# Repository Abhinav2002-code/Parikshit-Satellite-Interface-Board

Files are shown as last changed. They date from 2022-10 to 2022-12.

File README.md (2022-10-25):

# PA Interface Board

This is the Interface board for performance  
assurance of the Parikshit Student Satellite.

## About the project

The Parikshit Student satellite is a team of 25 undergraduates skilled in building nanosatellites.  
This PCB is a card used as an interface between  
the testing jigs in the teams lab and the nanosatellite system.

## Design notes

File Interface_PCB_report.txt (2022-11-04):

PCB statistics report
=====================
- Date: 03-11-2022 20:04:57
- Project: Interface_PCB
- Board name: Interface_PCB

Board
-----
- Width: 1822.62 mils
- Height: 1877.36 mils
- Area: 3204333.08 sq. mils

Pads
----
- Through hole: 3
- SMD: 180
- Connector: 0
- NPTH: 4

Vias
----
- Through vias: 46
- Blind/buried: 0
- Micro vias: 0

Components
----------

| | Front Side | Back Side | Total |
|---|---|---|---|
|THT: | 1  | 0  | 1  |
|SMD: | 37  | 0  | 37  |
|Total:  | 38  | 0  | 38  |
| | | | |

Drill holes
-----------

| Count | Shape | X Size | Y Size | Plated | Via/Pad | Start Layer | Stop Layer |
|---|---|---|---|---|---|---|---|
| 42 | Round | 15.75 mils | 15.75 mils | PTH | Via | F.Cu | B.Cu |
| 4 | Round | 82.68 mils | 82.68 mils | NPTH | Pad | F.Cu | B.Cu |
| 4 | Round | 11.81 mils | 11.81 mils | PTH | Via | F.Cu | B.Cu |
| 2 | Round | 51.18 mils | 51.18 mils | PTH | Pad | F.Cu | B.Cu |
| 1 | Round | 47.64 mils | 47.64 mils | PTH | Pad | F.Cu | B.Cu |

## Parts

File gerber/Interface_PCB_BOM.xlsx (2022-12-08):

Id | Quantity | Designator | Package | Designation | Supplier and ref
1 | 4 | J1,J2,J3,J4 | 502382-0470 | Conn_01x04 | element14 - https://in.element14.com/molex/502382-0470/connector-rcpt-4pos-1row-1-25mm/dp/1620786?st=5023820470
2 | 4 | CB3,CB2,CB1,CB4 | C_0805_2012Metric | 4.7u | mouser - https://www.mouser.in/ProductDetail/KEMET/C0805C475K3RACTU?qs=PzGy0jfpSMsRb1o8vMQxfQ%3D%3D
3 | 4 | H2,H3,H1,H4 | MountingHole_2.1mm | MountingHole
4 | 5 | CD6,CD3,CD5,CD2,CD4 | C_0402_1005Metric | 100n | mouser - https://www.mouser.in/ProductDetail/KEMET/C0402C104M4PACTU?qs=K5ytOU5dogo1QkNDOJRLDg%3D%3D
5 | 2 | CMS1,CMS3 | C_0805_2012Metric | 10n | mouser - https://www.mouser.in/ProductDetail/KEMET/C0805C103K8RACAUTO?qs=MyNHzdoqoQL%2F3d5ufVgX2g%3D%3D
6 | 1 | IC1 | QFP50P1200X1200X160-64N | STM32L412RBT6P | mouser - https://www.mouser.in/ProductDetail/STMicroelectronics/STM32L412RBT6P?qs=l7cgNqFNU1hh%252BU1wOZs5Xg%3D%3D
7 | 1 | CMS2 | C_0805_2012Metric | 1u | mouser - https://www.mouser.in/ProductDetail/KEMET/C0805X105K5RACAUTO?qs=HBWAp0VN4Rg97tWg6%252BgIPg%3D%3D
8 | 1 | J6 | 693072010801 | Micro_SD_Card | mouser - https://www.mouser.in/ProductDetail/Wurth-Elektronik/693072010801?qs=7gQLVZk5cPmw4uU1mAcUFg%3D%3D
9 | 3 | CR2,CR1,CR3 | C_0402_1005Metric | 22uF | mouser - https://www.mouser.in/ProductDetail/Taiyo-Yuden/AMK105EBJ226MV-F?qs=gZXFycFWdAObGy%252BzTmkIrw%3D%3D
10 | 1 | Y2 | ECS80830QVSTR | Crystal | mouser - https://www.mouser.in/ProductDetail/ECS/ECS-80-8-30Q-VS-TR?qs=T3oQrply3y8AmzaMN9qXDQ%3D%3D
11 | 1 | RExt1 | R_0603_1608Metric | 2K | mouser - https://www.mouser.in/ProductDetail/Bourns/CR0603-JW-202ELF?qs=QNvGIbmBFedJvqrSZNeMIw%3D%3D
12 | 2 | R2,R1 | R_0805_2012Metric | 1k | mouser - https://www.mouser.in/ProductDetail/Bourns/CR0805-FX-1001ELF?qs=tknLyCMIRbOJasvgRv5Bdg%3D%3D
13 | 2 | Cl1,Cl2 | C_0402_1005Metric | 2pF | mouser - https://www.mouser.in/ProductDetail/KEMET/C0402C209D5GACAUTO?qs=Cqqh%252BS766wl%2FF1D1Q0LwKg%3D%3D
14 | 1 | Y1 | ABS05W32768KHZD2T | Crystal | element14 - https://in.element14.com/abracon/abs05-32-768khz-t/crystal-32-768khz-12-5pf-1-6-x/dp/2467859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
15 | 2 | RSPI1,RSPI2 | R_0402_1005Metric | 1K | mouser - https://www.mouser.in/ProductDetail/Bourns/CR0402AFX-1001GLF?qs=GedFDFLaBXGtEgTtdRRFew%3D%3D
16 | 2 | D2,D1 | LED_0805_2012Metric | LED_Small | mouser - https://www.mouser.in/ProductDetail/Wurth-Elektronik/150080BS75000?qs=2kOmHSv6VfT2tBo3UPVqAQ%3D%3D
17 | 2 | Cl4,Cl3 | C_0402_1005Metric | 10pF | mouser - https://www.mouser.in/ProductDetail/KEMET/C0402C100K5RACAUTO?qs=hzBznG4dWXWvk2ClWTGJYg%3D%3D
18 | 2 | LR1,LMS1 | L_0805_2012Metric | 39nH | mouser - https://www.mouser.in/ProductDetail/ABRACON/AIMC-0805-39NJ-T?qs=1vO2EIVe%252BY6yKg%252Bn%252BCAmog%3D%3D
19 | 1 | CD1 | C_0402_1005Metric | 4.7u | mouser - https://www.mouser.in/ProductDetail/KEMET/C0402C475M9PACTU?qs=x4XeXhDQKnr0GX0Xu9DUoQ%3D%3D
20 | 1 | U1 | SOT-223-3_TabPin2 | AMS1117-3.3 | electronics comp - https://www.electronicscomp.com/ams1117-3.3v-voltage-regulator-smd-sot-23-package-india
21 | 1 | J5 | FTSH10501LDVK | AVR-JTAG-10 | mouser - https://www.mouser.in/ProductDetail/Samtec/FTSH-105-01-L-DV-K?qs=%252B5JSS813miOqo3Vy%252BvhCFg%3D%3D
22 | 1 | J7 | GMCB05B11124H1EU | USB_B | mouser - https://www.mouser.in/ProductDetail/Amphenol-Commercial-Products/GMCB05B11124H1EU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
23 | 1 | NT1 | NetTie-3_SMD_Pad2.0mm | NetTie_3_Tee
24 | 1 | DEXT1 | AQ120501ETG | D_Schottky | mouser - https://www.mouser.in/ProductDetail/Littelfuse/AQ1205-01ETG?qs=TCDPyi3sCW2VfoQH%2FYUj8g%3D%3D
25 | 1 | J8 | PinHeader | Conn_01x02_Male | mouser - https://www.mouser.in/ProductDetail/Harwin/M20-9990246?qs=Jph8NoUxIfWjw4WmyRvzag%3D%3D

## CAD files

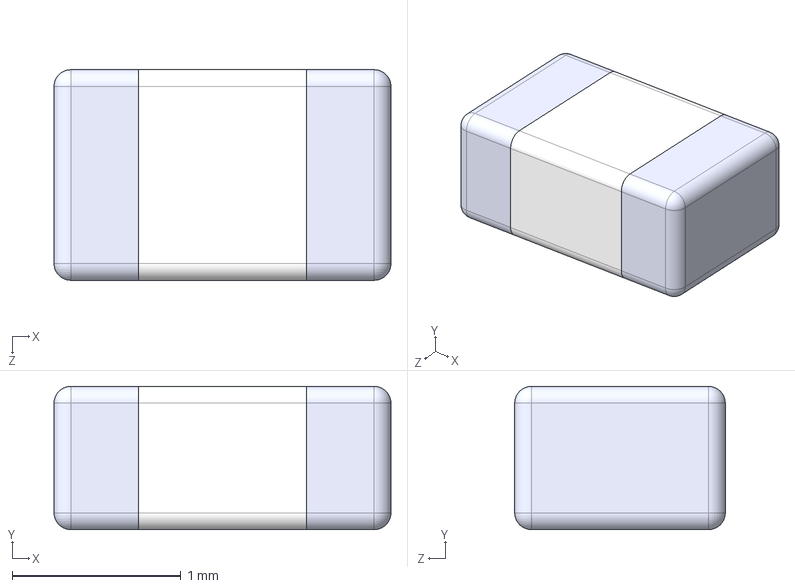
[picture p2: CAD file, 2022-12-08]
AIMC-0805-39NJ-T.STEP
2.00 x 0.85 x 1.25 mm

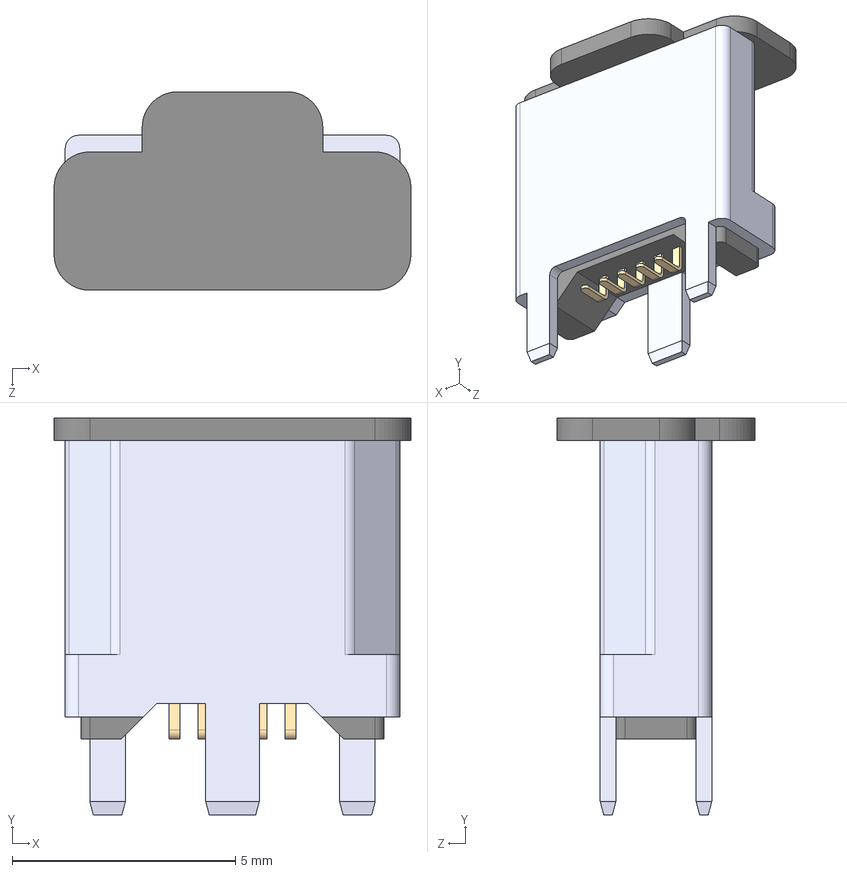
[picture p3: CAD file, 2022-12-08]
GMCB05B11124H1EU (1)/GMCB05B11124H1EU.step
8.00 x 8.90 x 4.45 mm
GMCB05B11124H1EU-Housing
GMCB05B11124H1EU-Pin x 5
GMCB05B11124H1EU-Shell

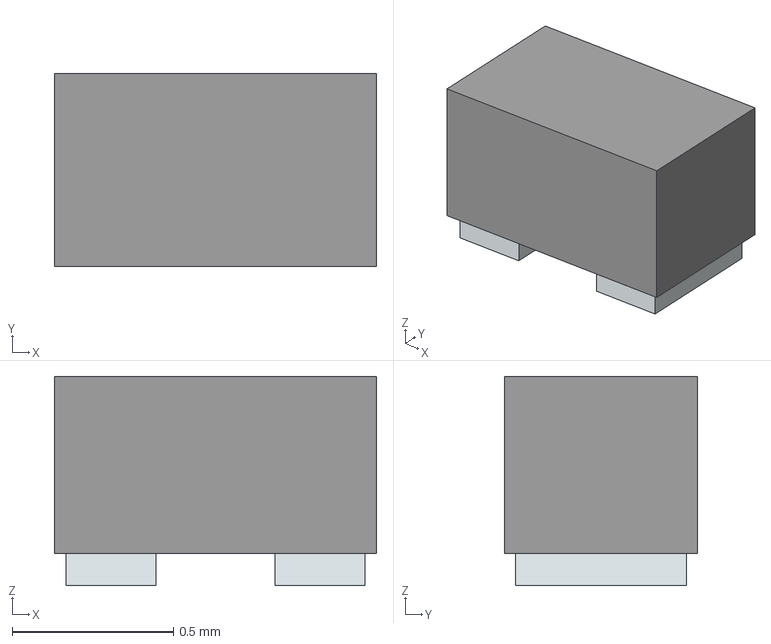
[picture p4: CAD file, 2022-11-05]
AQ1205-01ETG.stp
1.00 x 0.6 x 0.65 mm
Pins

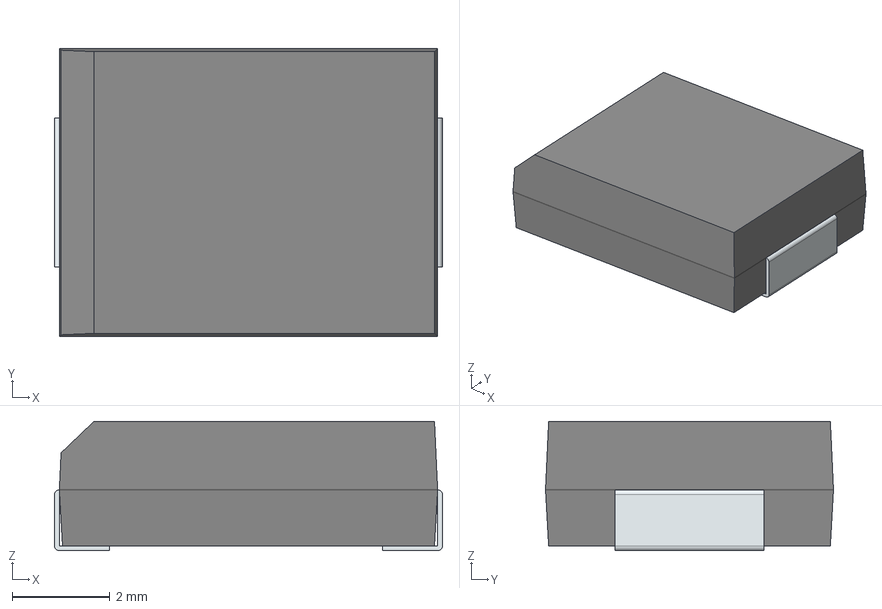
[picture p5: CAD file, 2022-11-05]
SMC50J58A.stp
7.95 x 5.90 x 2.65 mm
FilletPin1
FilletPin2

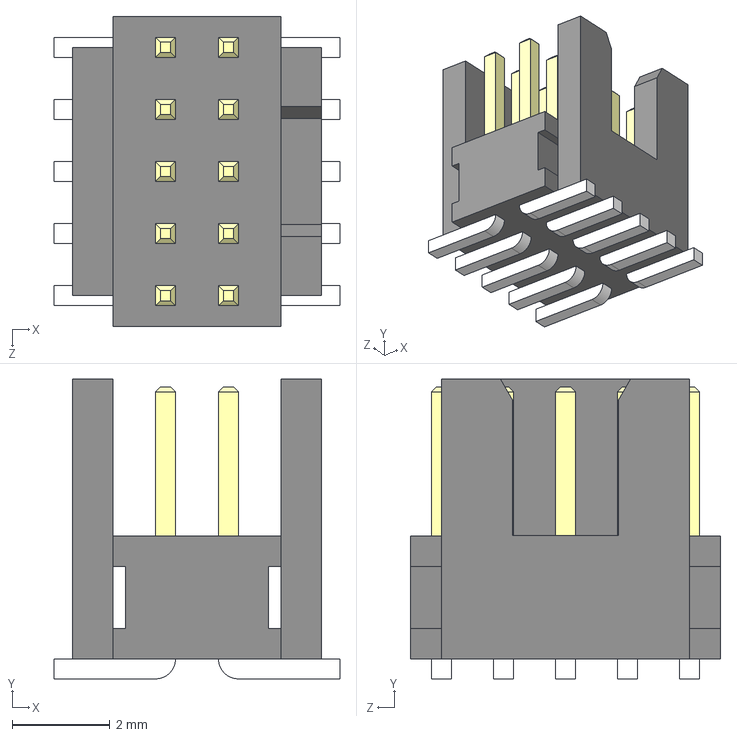
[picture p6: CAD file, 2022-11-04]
FTSH-105-01-L-DV-K.stp
5.85 x 6.13 x 6.35 mm

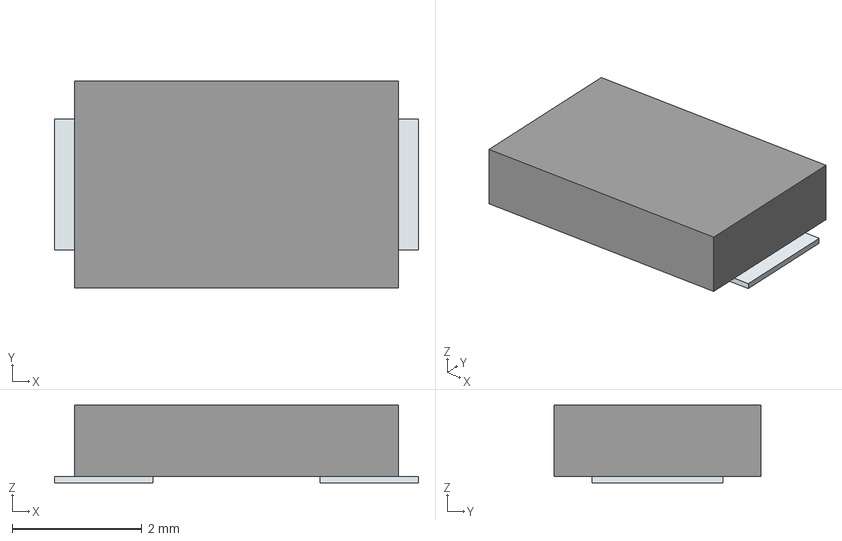
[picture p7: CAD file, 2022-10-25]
ECS-80-8-30Q-VS-TR.stp
5.62 x 3.20 x 1.20 mm
Pins

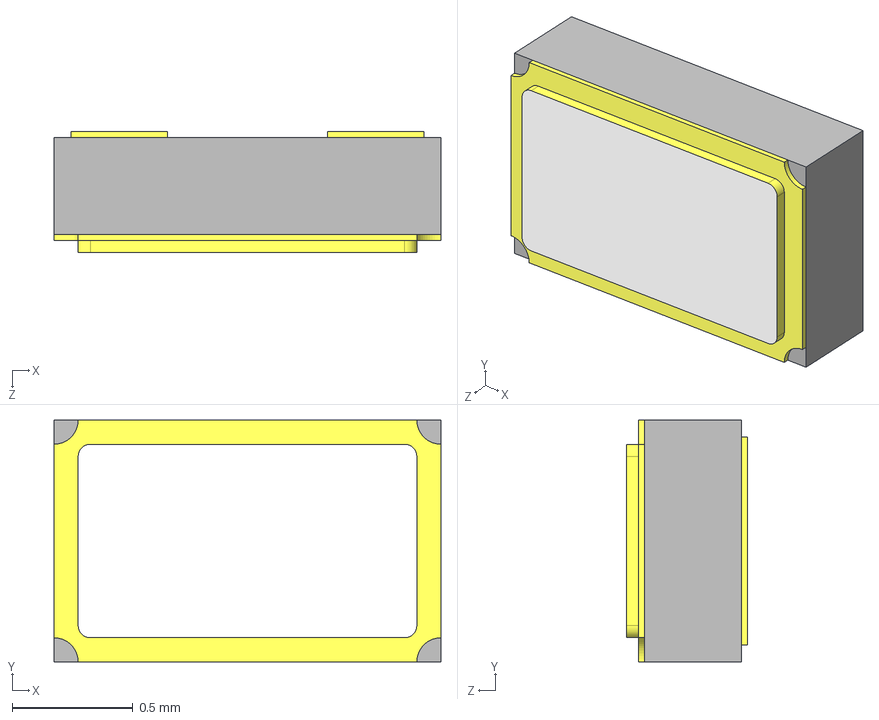
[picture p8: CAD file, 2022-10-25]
ABS05W-32.768KHZ-D-2-T.stp
1.60 x 1.00 x 0.5 mm

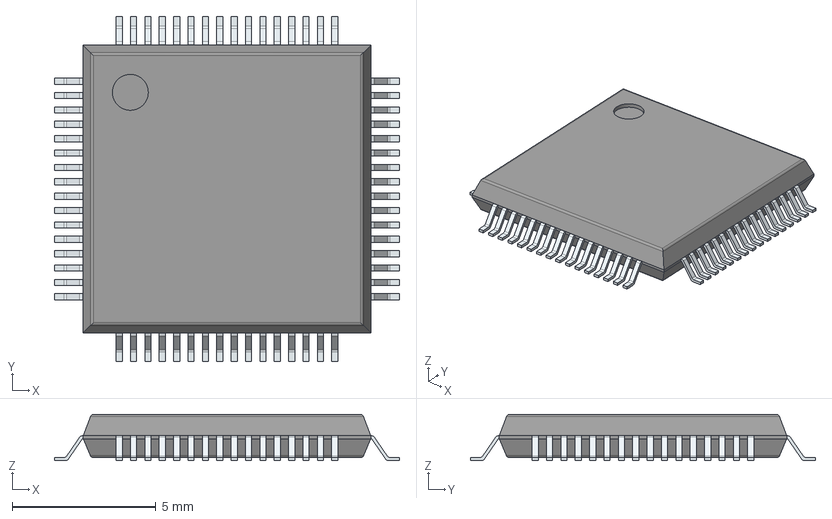
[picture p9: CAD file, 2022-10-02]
STM32L412RBT6P.stp
12.0 x 12.0 x 1.60 mm
PinsArrayLR
PinsArrayTB

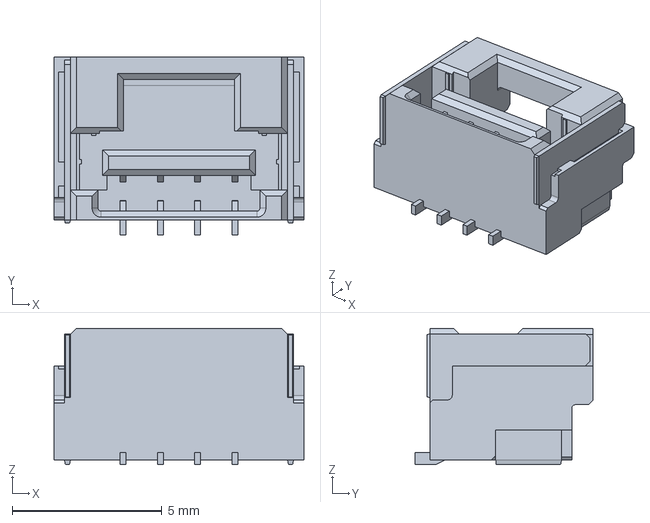
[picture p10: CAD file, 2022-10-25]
502382-0470.stp
8.35 x 5.94 x 4.55 mm

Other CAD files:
STM32L412RBT6P/Allegro/qfp50p1200x1200x160-64n.psm
STM32L412RBT6P/DEHDL/stm32l412rbt6p/chips/chips.prt

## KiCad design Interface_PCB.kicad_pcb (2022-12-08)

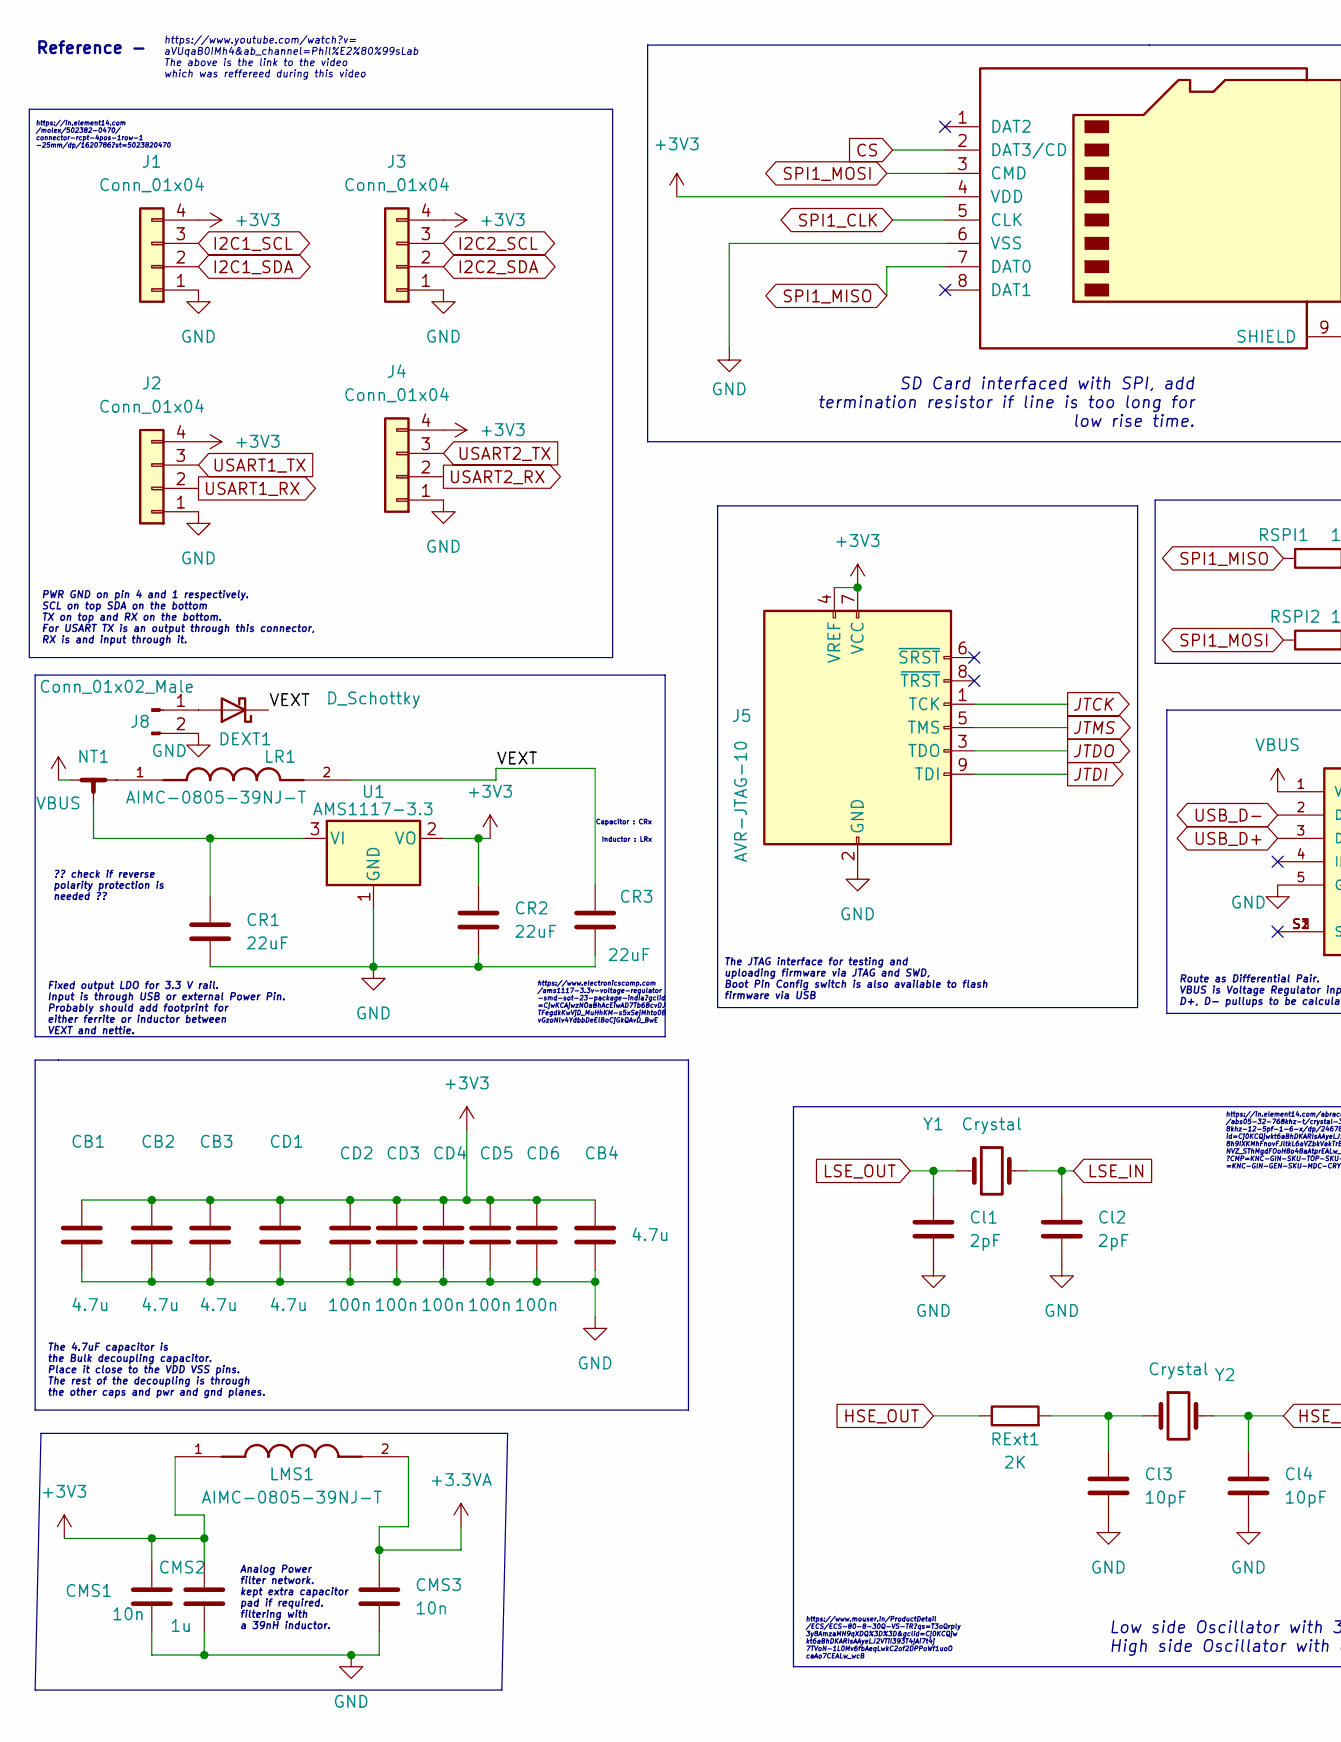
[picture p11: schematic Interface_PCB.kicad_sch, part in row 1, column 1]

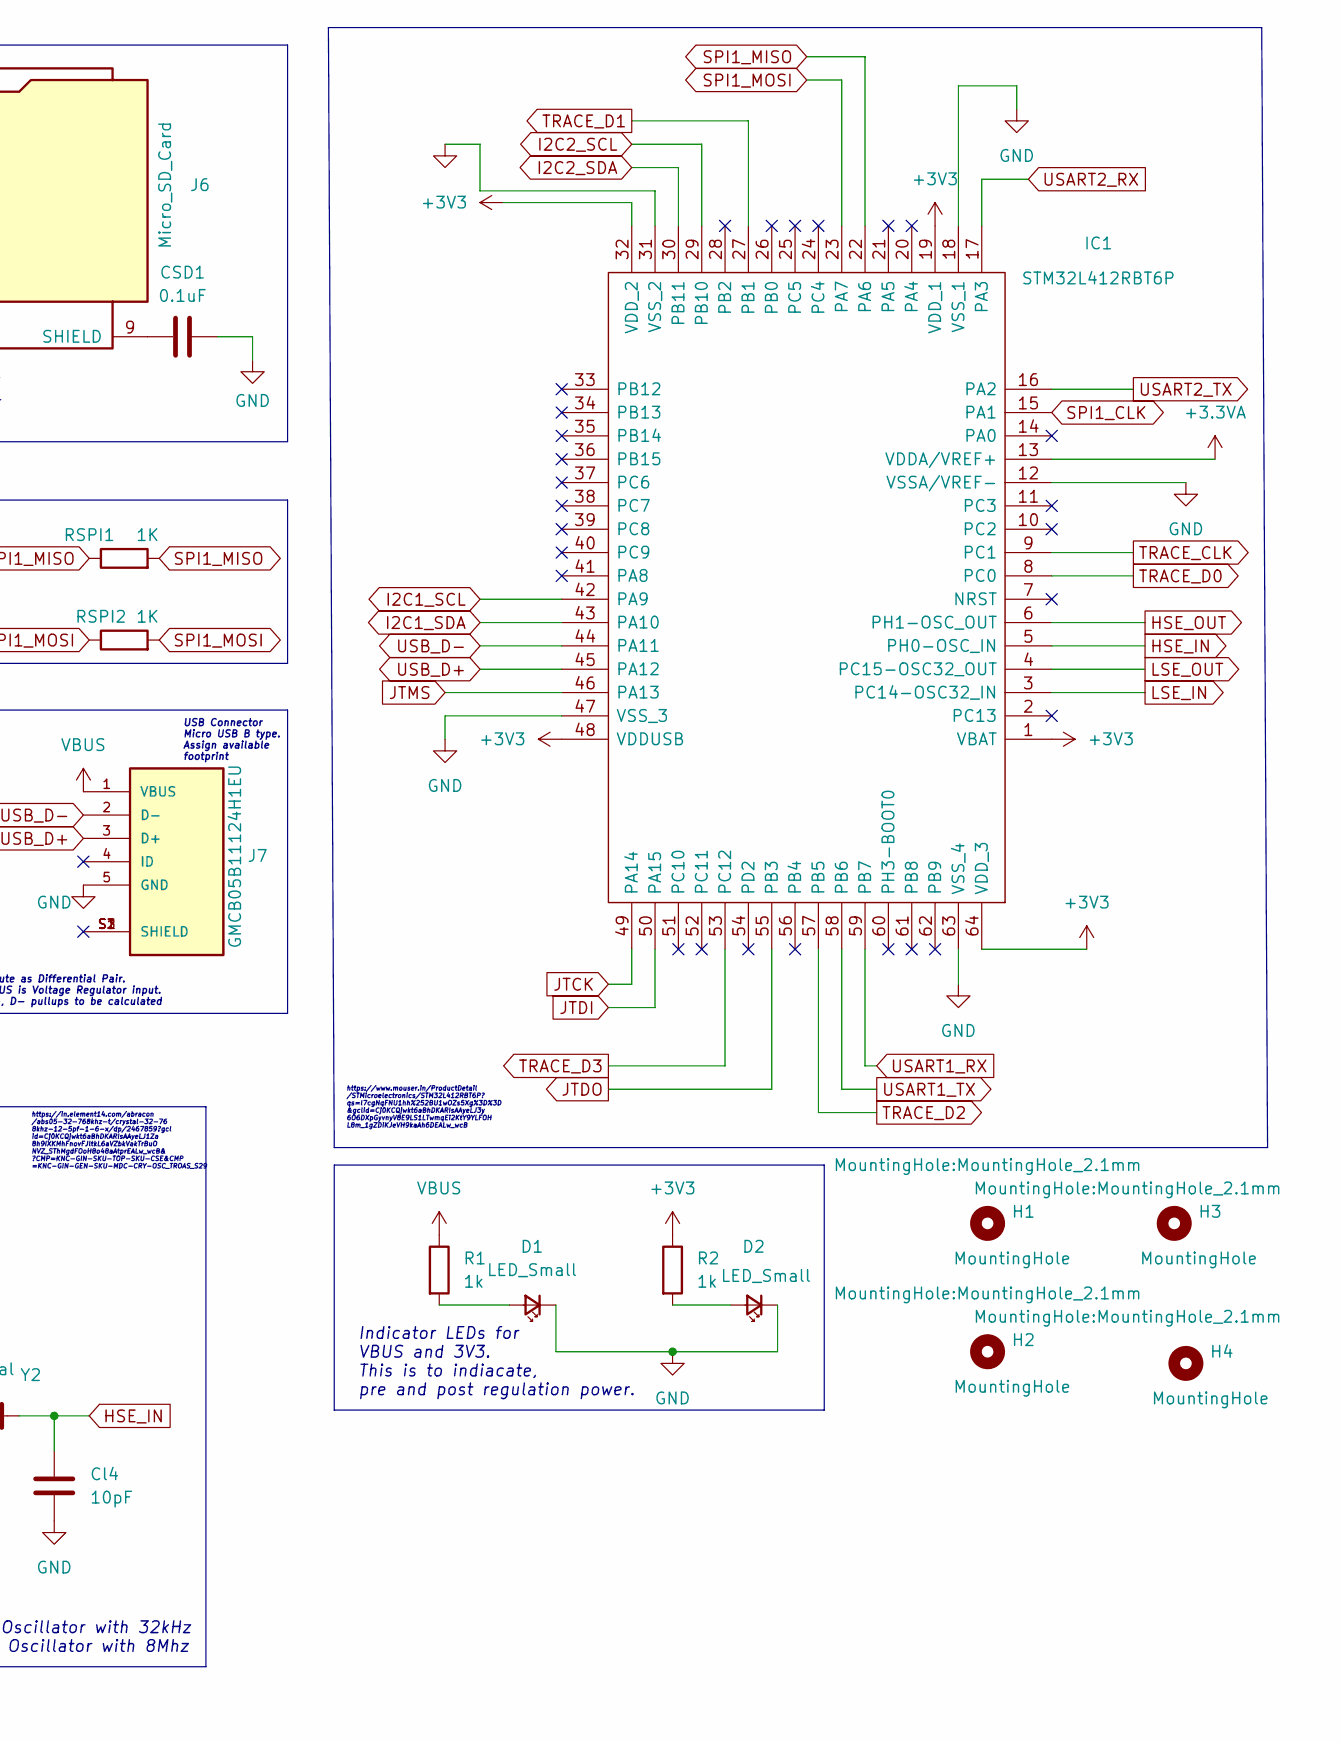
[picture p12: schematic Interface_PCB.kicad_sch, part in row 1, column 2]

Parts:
CB1, CB2, CB3, CB4: 4.7u; C_0805_2012Metric
CD1: 4.7u; C_0402_1005Metric
CD2, CD3, CD4, CD5, CD6: 100n; C_0402_1005Metric
CMS1, CMS3: 10n; C_0805_2012Metric
CMS2: 1u; C_0805_2012Metric
CR1, CR2, CR3: 22uF; C_0402_1005Metric
CSD1: 0.1uF; C_0402_1005Metric
Cl1, Cl2: 2pF; C_0402_1005Metric
Cl3, Cl4: 10pF; C_0402_1005Metric
D1, D2: LED_Small; LED_0805_2012Metric
DEXT1: D_Schottky; AQ120501ETG
H1, H2, H3, H4: MountingHole; MountingHole_2.1mm
IC1: STM32L412RBT6P; QFP50P1200X1200X160-64N; Mouser Part Number 511-STM32L412RBT6P
J1, J2, J3, J4: Conn_01x04; 502382-0470
J5: AVR-JTAG-10; FTSH10501LDVK
J6: Micro_SD_Card; 693072010801
J7: GMCB05B11124H1EU; AMPHENOL_GMCB05B11124H1EU; PARTREV C
J8: Conn_01x02_Male; PinHeader_1x02_P2.54mm_Vertical
LMS1: AIMC-0805-39NJ-T; INDC2012X105N
LR1: AIMC-0805-39NJ-T; INDC2012X105N
NT1: NetTie_3_Tee; NetTie-3_SMD_Pad2.0mm
R1, R2: 1k; R_0805_2012Metric
RExt1: 2K; R_0603_1608Metric
RSPI1, RSPI2: 1K; R_0402_1005Metric
U1: AMS1117-3.3; SOT-223-3_TabPin2
Y1: Crystal; ABS05W32768KHZD2T
Y2: Crystal; ECS80830QVSTR

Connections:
+3.3VA: CMS3.1, IC1.13 (VDDA/VREF+), LMS1.2
+3V3: CB1.1, CB2.1, CB3.1, CB4.1, CD1.1, CD2.1, CD3.1, CD4.1, CD5.1, CD6.1, CMS1.1, CMS2.1, CR2.1, IC1.1 (VBAT), IC1.19 (VDD_1), IC1.32 (VDD_2), IC1.48 (VDDUSB), IC1.64 (VDD_3), J1.4, J2.4, J3.4, J4.4, J5.4 (VREF), J5.7 (VCC), J6.4 (VDD), LMS1.1, R2.1, U1.2 (VO)
/VEXT: CR3.1, DEXT1.1 (K), LR1.2
CS: J6.2 (DAT3/CD)
GND: CB1.2, CB2.2, CB3.2, CB4.2, CD1.2, CD2.2, CD3.2, CD4.2, CD5.2, CD6.2, CMS1.2, CMS2.2, CMS3.2, CR1.2, CR2.2, CR3.2, CSD1.2, Cl1.2, Cl2.2, Cl3.2, Cl4.2, D1.1 (K), D2.1 (K), IC1.12 (VSSA/VREF-), IC1.18 (VSS_1), IC1.31 (VSS_2), IC1.47 (VSS_3), IC1.63 (VSS_4), J1.1, J2.1, J3.1, J4.1, J5.2 (GND), J5.10 (GND), J6.6 (VSS), J7.5 (GND), J8.2, U1.1 (GND)
HSE_IN: Cl4.1, IC1.5 (PH0-OSC_IN), Y2.2
HSE_OUT: IC1.6 (PH1-OSC_OUT), RExt1.1
I2C1_SCL: IC1.42 (PA9), J1.3
I2C1_SDA: IC1.43 (PA10), J1.2
I2C2_SCL: IC1.29 (PB10), J3.3
I2C2_SDA: IC1.30 (PB11), J3.2
JTCK: IC1.49 (PA14), J5.1 (TCK)
JTDI: IC1.50 (PA15), J5.9 (TDI)
JTDO: IC1.55 (PB3), J5.3 (TDO)
JTMS: IC1.46 (PA13), J5.5 (TMS)
LSE_IN: Cl2.1, IC1.3 (PC14-OSC32_IN), Y1.2
LSE_OUT: Cl1.1, IC1.4 (PC15-OSC32_OUT), Y1.1
unnamed: CR1.1, NT1.3, U1.3 (VI)
unnamed: CSD1.1, J6.9 (SHIELD)
unnamed: Cl3.1, RExt1.2, Y2.1
unnamed: D1.2 (A), R1.2
unnamed: D2.2 (A), R2.2
unnamed: DEXT1.2 (A), J8.1
unnamed: LR1.1, NT1.2
SPI1_CLK: IC1.15 (PA1), J6.5 (CLK)
SPI1_MISO: IC1.22 (PA6), J6.7 (DAT0), RSPI1.1, RSPI1.2
SPI1_MOSI: IC1.23 (PA7), J6.3 (CMD), RSPI2.1, RSPI2.2
TRACE_CLK: IC1.9 (PC1)
TRACE_D0: IC1.8 (PC0)
TRACE_D1: IC1.27 (PB1)
TRACE_D2: IC1.57 (PB5)
TRACE_D3: IC1.53 (PC12)
USART1_RX: IC1.59 (PB7), J2.2
USART1_TX: IC1.58 (PB6), J2.3
USART2_RX: IC1.17 (PA3), J4.2
USART2_TX: IC1.16 (PA2), J4.3
USB_D+: IC1.45 (PA12), J7.3 (D+)
USB_D-: IC1.44 (PA11), J7.2 (D-)
VBUS: J7.1 (VBUS), NT1.1, R1.1

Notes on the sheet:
Fixed output LDO for 3.3 V rail. Input is through USB or external Power Pin. Probably should add footprint for either ferrite or inductor between VEXT and nettie.
USB Connector Micro USB B type. Assign available footprint
The JTAG interface for testing and uploading firmware via JTAG and SWD, Boot Pin Config switch is also available to flash firmware via USB
Capacitor : CRx
SD Card interfaced with SPI, add termination resistor if line is too long for low rise time.
?? check if reverse polarity protection is needed ??
Reference -
Indicator LEDs for VBUS and 3V3. This is to indiacate, pre and post regulation power.
https://www.mouser.in/ProductDetail /STMicroelectronics/STM32L412RBT6P? qs=l7cgNqFNU1hh%252BU1wOZs5Xg%3D%3D &gclid=Cj0KCQjwkt6aBhDKARIsAAyeLJ3y 6O6DXpGyvnyV8E9LS1LTwmqEi2KtY9YLFOH L8m_1gZDiKJeVH9kaAh6DEALw_wcB
https://in.element14.com/abracon /abs05-32-768khz-t/crystal-32-76 8khz-12-5pf-1-6-x/dp/2467859?gcl id=Cj0KCQjwkt6aBhDKARIsAAyeLJ1Za 8h9IXKMhFnovFJltkL6aVZbkVakTrBuO NVZ_SThMgdFOoH8o48aAtprEALw_wcB& ?CMP=KNC-GIN-SKU-TOP-SKU-CSE&CMP =KNC-GIN-GEN-SKU-MDC-CRY-OSC_TROAS_S29
https://www.youtube.com/watch?v= aVUqaB0IMh4&ab_channel=Phil%E2%80%99sLab The above is the link to the video which was reffereed during this video
Analog Power filter network. kept extra capacitor pad if required. filtering with a 39nH inductor.
Low side Oscillator with 32kHz High side Oscillator with 8Mhz
Route as Differential Pair. VBUS is Voltage Regulator input. D+, D- pullups to be calculated
https://www.mouser.in/ProductDetail /ECS/ECS-80-8-30Q-VS-TR?qs=T3oQrply 3y8AmzaMN9qXDQ%3D%3D&gclid=Cj0KCQjw kt6aBhDKARIsAAyeLJ2VTiI393T4jAi7t4j 7TVoN-1L0Mv6fbAeqLwkC2of2DPPoWf1uoO caAo7CEALw_wcB
https://www.electronicscomp.com /ams1117-3.3v-voltage-regulator -smd-sot-23-package-india?gclid =CjwKCAjwzNOaBhAcEiwAD7Tb6BcvDJ TFegdkKwVjD_MuHhKM-s5xSejMhto0B vGzoNlv4YdbbDeElBoCjGkQAvD_BwE
https://in.element14.com /molex/502382-0470/ connector-rcpt-4pos-1row-1 -25mm/dp/1620786?st=5023820470
Inductor : LRx
PWR GND on pin 4 and 1 respectively. SCL on top SDA on the bottom TX on top and RX on the bottom. For USART TX is an output through this connector, RX is and input through it.
The 4.7uF capacitor is the Bulk decoupling capacitor. Place it close to the VDD VSS pins. The rest of the decoupling is through the other caps and pwr and gnd planes.

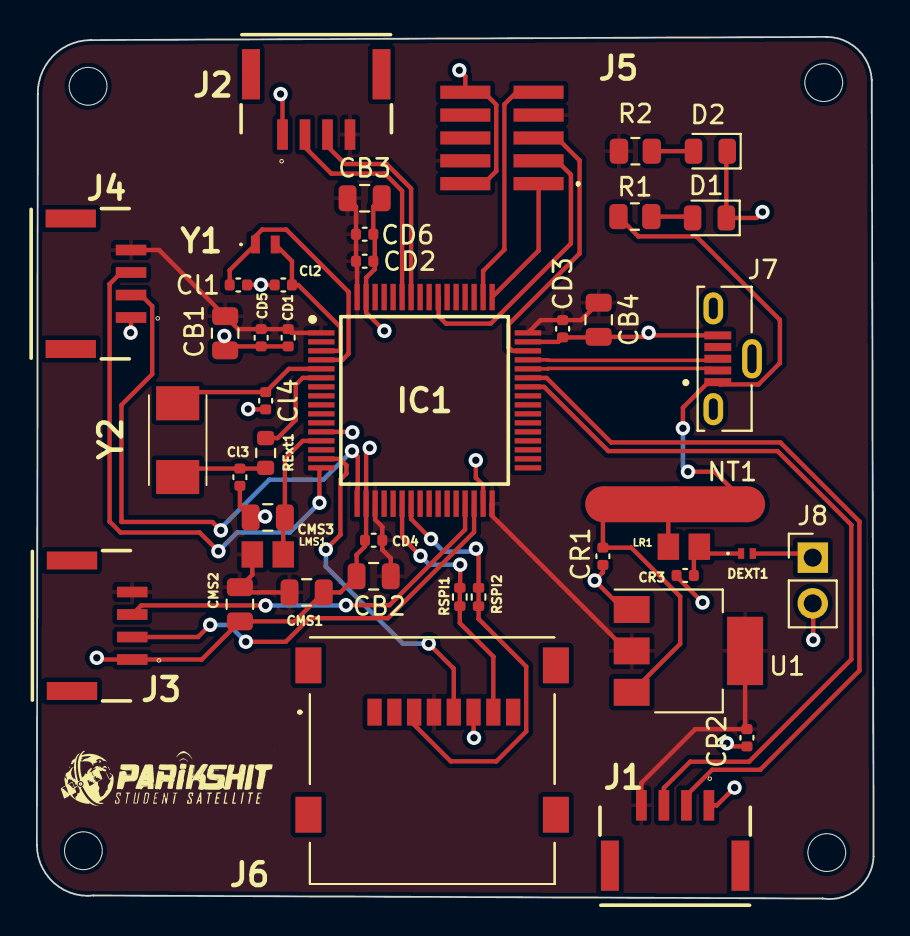
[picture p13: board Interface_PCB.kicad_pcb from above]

Board: 2 copper layers, 46.5 x 47.9 mm, 47 parts (0 on the bottom side), 32 nets.

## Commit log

2022-10-02 Interface Board Schematic
    [EDI2CAP.CFG, Interface_PCB.kicad_pcb, Interface_PCB.kicad_sch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]
2022-10-03 Indicator LEDs added and AMS1117 added but not connected
2022-10-03 AMS connected
    [Interface_PCB.kicad_sch]
2022-10-03 Added crystal configs to schematic
    [Interface_PCB.kicad_sch]
2022-10-04 Full Schematic Rev 1.0
2022-10-04 Final Schematic done, footprint assignment TBD
    [Interface_PCB.kicad_sch]
2022-10-04 Components are on PCB doc, Stackup and Layout to be done, verify footprints
    [Interface_PCB.kicad_sch]
2022-10-23 Caps and inductors annotated properly, regulator changed to fixed regulator, resource links added
2022-10-25 Added all component links and modified the footprints
    [502382-0470.stp, ABS05W-32.768KHZ-D-2-T.stp, ECS-80-10-30B-CKM-TR.stp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]
2022-10-28 Layout Revision 1
    [Interface_PCB.kicad_pcb, Interface_PCB.kicad_sch]
2022-10-28 Layout rev 1.1
    [Interface Board.xlsx]
2022-10-29 Footprint zip files added
2022-10-29 Layout rev2.0
    [Interface_PCB.kicad_pcb]
2022-11-02 Layout rev3.0 - redesigned
    [Interface_PCB.kicad_pcb, Interface_PCB.kicad_sch]
2022-11-04 Design rev4.0
    [FTSH-105-01-L-DV-K.stp, Interface_PCB.kicad_pcb, Interface_PCB.kicad_sch]
2022-11-04 got rid of gnd parasitic vias around USB diff pair
    [Interface_PCB.kicad_pcb]
2022-11-04 Edge cuts are improved
    [Interface_PCB.kicad_pcb]
2022-11-04 Design rev 4.1
    [Interface_PCB.kicad_pcb]
2022-11-04 Resistor pads to SD card connector
    [Interface_PCB.kicad_pcb, Interface_PCB.kicad_sch]
2022-11-04 Added BOM, position and gerber files
    [Interface_PCB-B_Cu.gbr, Interface_PCB-B_Mask.gbr, Interface_PCB-B_Paste.gbr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]
2022-11-05 Added TVS diode and External Voltage (BOM and gerber included)
    [AQ1205-01ETG.stp, Interface Board.xlsx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]
2022-11-06 Corrected the annotations
    [ECS-80-10-30B-CKM-TR.stp, Interface_PCB.kicad_pcb, Interface_PCB_BOM.xlsx]
2022-11-06 Added Full BOM and gerber
    [Interface_PCB-B_Cu.gbr, Interface_PCB-B_Mask.gbr, Interface_PCB-B_Paste.gbr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]
2022-11-06 Oscillators are brought closer
    [Interface_PCB.kicad_pcb]
2022-11-06 Design 5.0
    [Interface_PCB-B_Cu.gbr, Interface_PCB-B_Mask.gbr, Interface_PCB-B_Paste.gbr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]
2022-12-08 Updated inductor and USB according to manufacturer
    [AIMC-0805-39NJ-T.STEP, AIMC-0805-39NJ-T.step, GMCB05B11124H1EU--3DModel-STEP-269445.STEP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]
